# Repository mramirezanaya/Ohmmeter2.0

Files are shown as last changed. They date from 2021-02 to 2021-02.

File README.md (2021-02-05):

# Ohmmeter2.0

## 3D RGB Resistor

First the cables are soldered to the LEDs and the LED is glued on the piece inside the band. Each of the bands are mounted and glued together to build the resistance.

In the space between the bands, the white reference LEDs are soldered in parallel.

All cables are passed from one to another so that they all exit through the last.

Finally the two ends are glued and the resistance is finished.

## Assembling the Box

After printing all the pieces, we passed the resistance wires through the hole and soldered the terminations and the wires of the LEDs and the potentiometer.

The pcb is soldered according to the diagram and we connect all the wires.

## Programming

A state machine has been implemented to differentiate the modes.

### 'A' mode - Value to color
A value is entered by keyboard, it goes through an algorithm that returns its commercial value and displays it in the 3D resistor.

The program remains on active standby until a keyboard event arrives and if it is different from 'D' it shows the value on the screen and saves it in an array.
When pressing 'D', the array with the resistor value is passed to the "valor_a_comercial" function that converts the value into a commercial value and then, this array is passed to the "mostrar_resistencia" function that turns on the RGB LEDs of the 3D resistor with the right colors.

### 'B' mode - Color to value
The colors are entered and the value is displayed on the screen and the colors in the 3D resistor.

A legend is shown on the screen with the values and the corresponding number. The program saves the colors coded with numbers in an array and when pressing 'D' it shows the resistor value. While the colors are being entered, the RGB led of the corresponding band lights up.

### 'C' mode - Ohmmeter
This mode reads through the terminals and shows the value on the screen and the colors in the 3D resistor.

In order to measure various ranges, a potentiometer has been used. In a loop, the value of the potentiometer is read and this value is used as a reference to measure the connected resistor.
This process is repeated every programmable time (600 ms).

## Supplies:
- Arduino Mega

- 4 RGB Leds

- 3 Red Leds

- 3 White Leds

- 4 x 4 Membrane Switch Keypad

- OLED Display I2C 128 x 64 pixels and 0.96 Inch

- 2 connection terminals for resistors

- Potentiometer 50kΩ

- Resistors

    - 1kΩ x1
    - 220Ω x3
    - 22kΩ x1
    - 68Ω x1
- Pre-drilled plate

- 4 screws

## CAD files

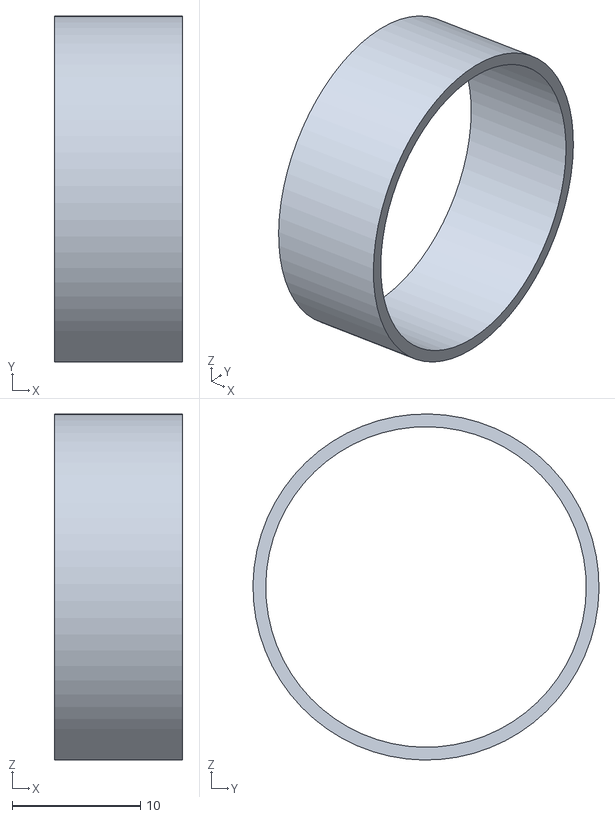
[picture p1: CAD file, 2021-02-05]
STLs/banda transparente.stl
10.0 x 27.0 x 27.0

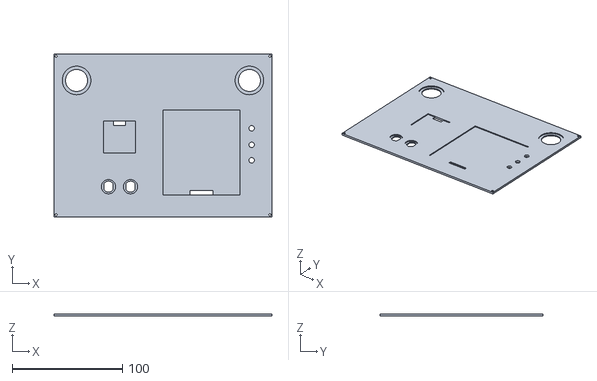
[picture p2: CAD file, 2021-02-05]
STLs/tapa.stl
198.0 x 148.0 x 2.00

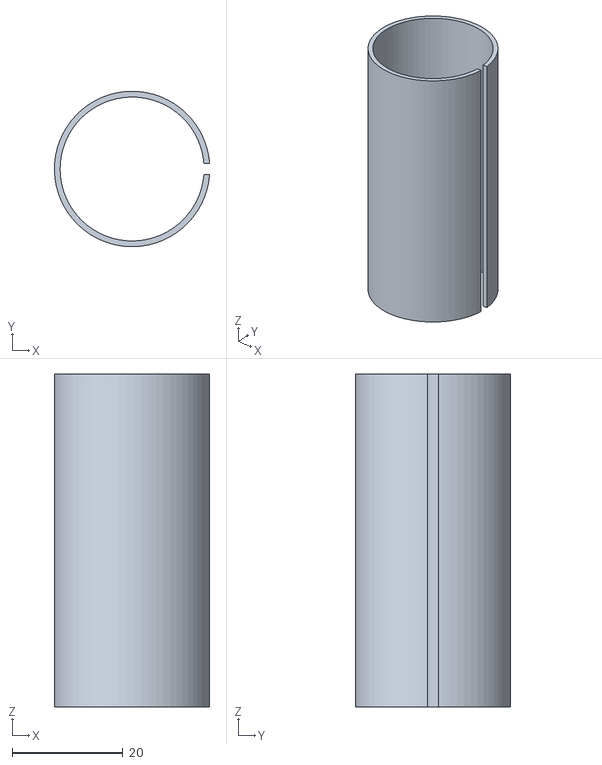
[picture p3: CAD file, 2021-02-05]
STLs/embellecedor.stl
28.0 x 28.0 x 60.0

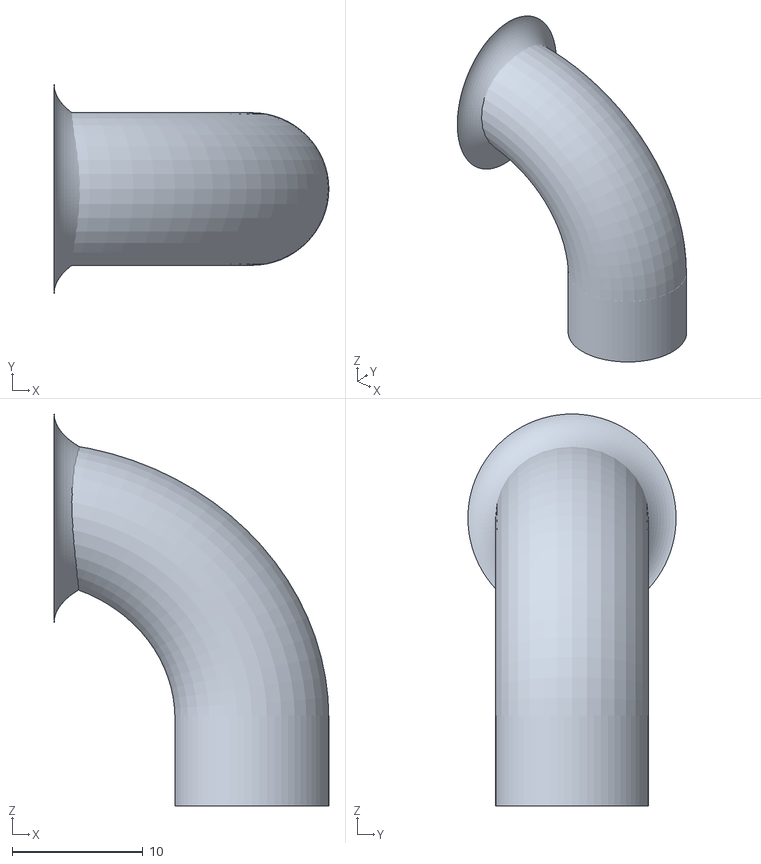
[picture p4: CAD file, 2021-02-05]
STLs/patilla.stl
21.0 x 15.9 x 30.0

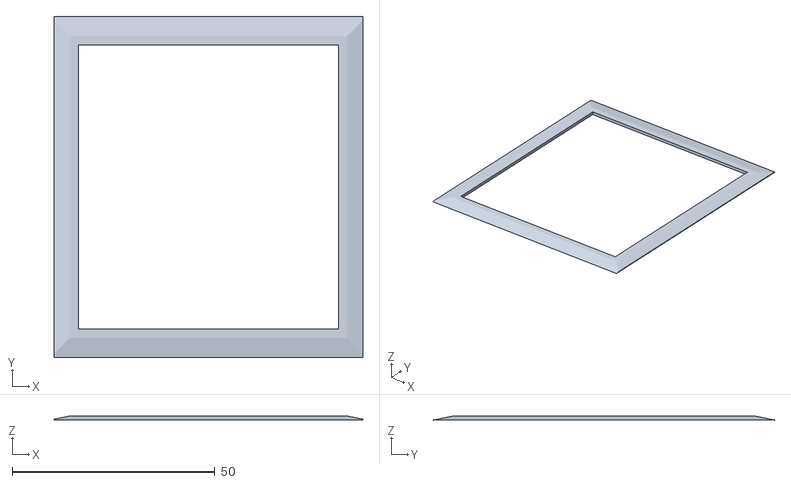
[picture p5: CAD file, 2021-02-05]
STLs/marco teclado.stl
76.0 x 84.0 x 1.00

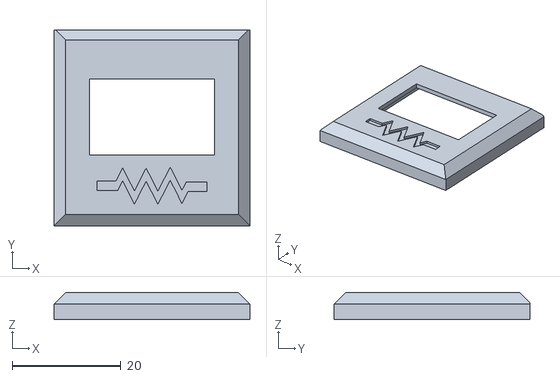
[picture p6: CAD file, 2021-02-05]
STLs/marco pantalla.stl
36.0 x 36.0 x 5.00

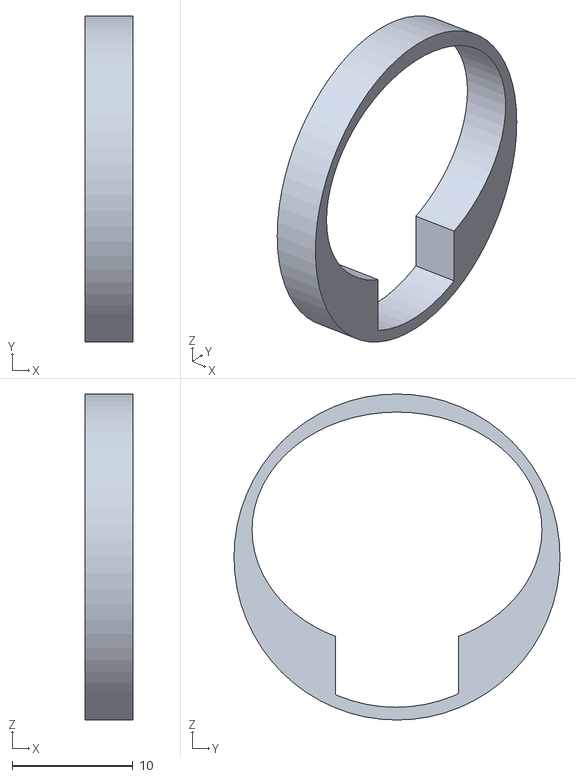
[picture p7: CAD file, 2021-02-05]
STLs/banda led blanco.stl
4.00 x 27.0 x 27.0

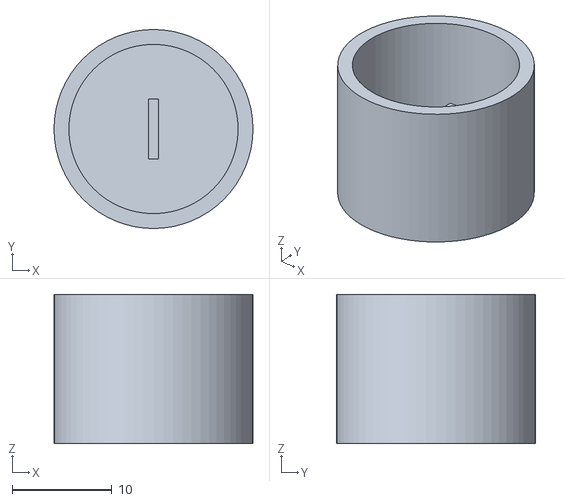
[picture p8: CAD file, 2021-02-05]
STLs/rueda.stl
20.0 x 20.0 x 15.0

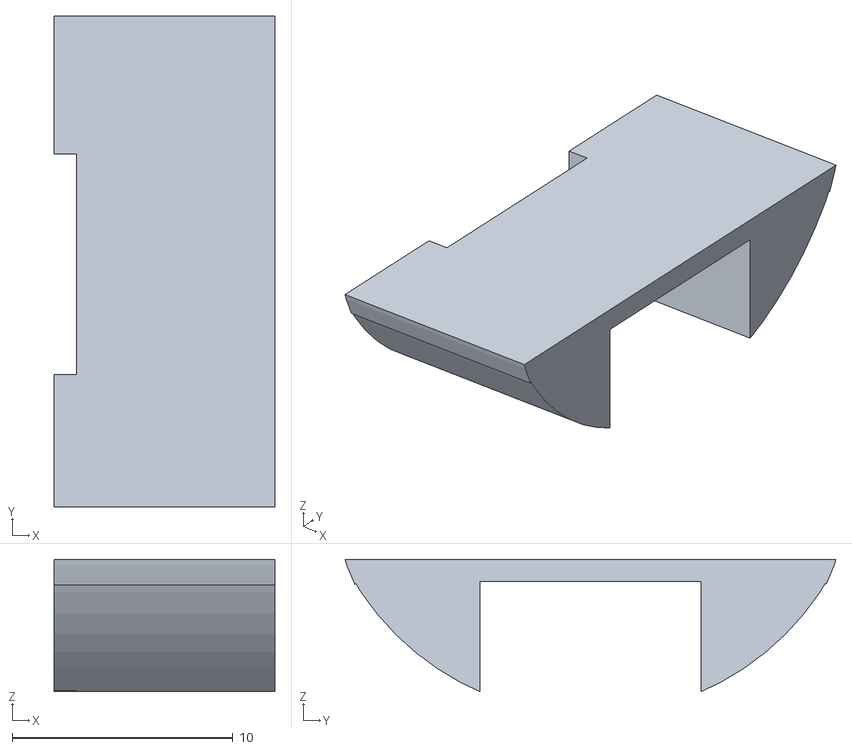
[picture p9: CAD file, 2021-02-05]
STLs/soporte led.stl
10.0 x 22.3 x 6.00

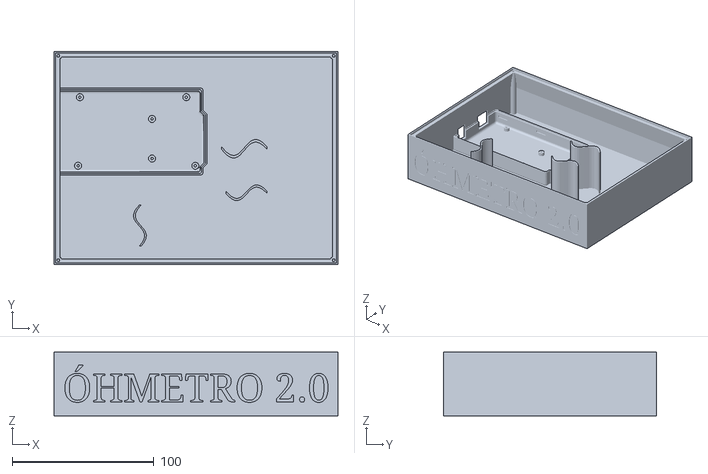
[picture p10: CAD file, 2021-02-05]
STLs/caja.stl
200.0 x 150.0 x 45.0

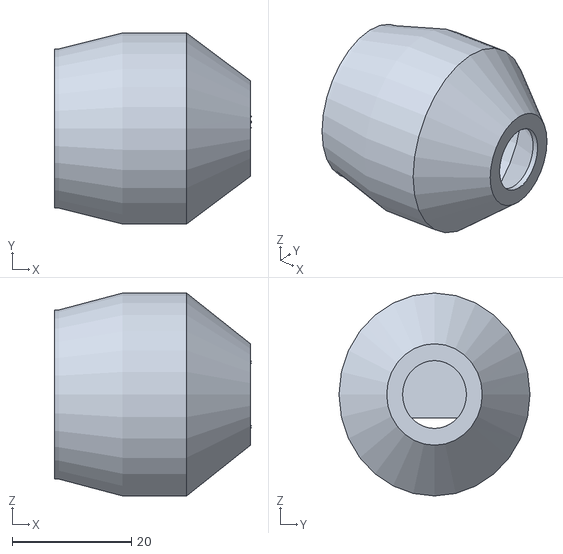
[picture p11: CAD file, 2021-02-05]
STLs/terminación.stl
33.0 x 32.0 x 34.0

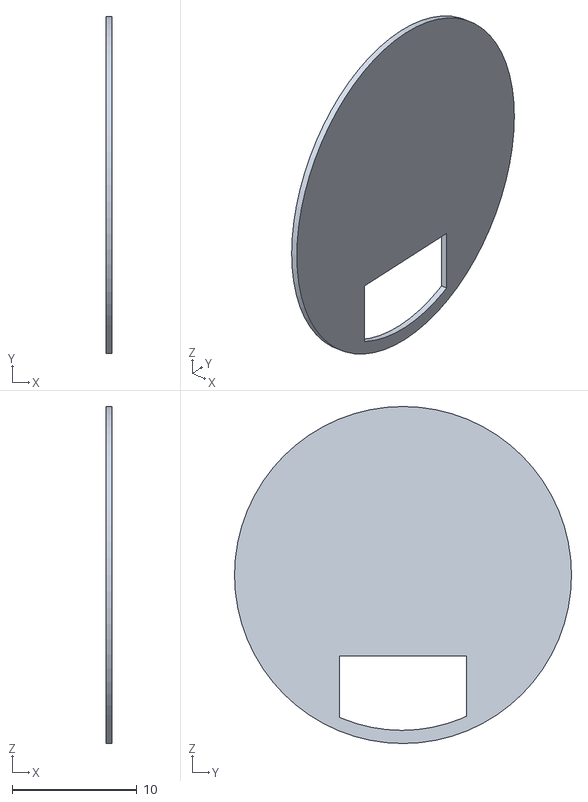
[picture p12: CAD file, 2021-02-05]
STLs/separador.stl
0.5 x 27.0 x 27.0

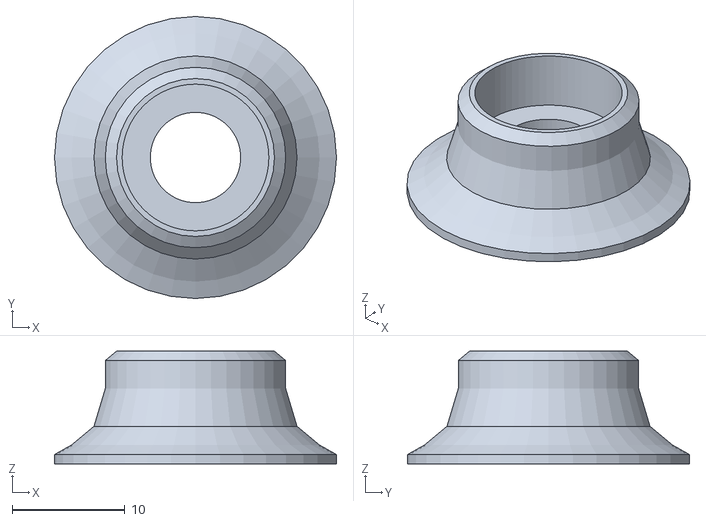
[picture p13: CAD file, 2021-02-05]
STLs/soporte resistencia.stl
25.0 x 25.0 x 10.0

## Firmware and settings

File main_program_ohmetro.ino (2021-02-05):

#include <SPI.h>
#include <Wire.h>
#include <Adafruit_GFX.h>
#include <Adafruit_SSD1306.h>
#include <Adafruit_Keypad.h>
 
// Definir constantes
#define ANCHO_PANTALLA 128 // ancho pantalla OLED
#define ALTO_PANTALLA 64 // alto pantalla OLED
#define BUFFER 20

#define BANDA1 1
#define BANDA2 2
#define BANDA3 3
#define BANDA4 4

#define modo_numero_a_color 0
#define modo_color_a_numero 1
#define modo_lee_resistencia 2
#define inicio 3

#define negro 0
#define marron 1
#define rojo 2
#define naranja 3
#define amarillo 4
#define verde 5
#define azul 6
#define violeta 7
#define gris 8
#define blanco 9

#define PERIODO 500

int x=0;
unsigned estado = inicio;

//globales del modo A
char a='x';
String cadena; 
char caracteres[BUFFER];
unsigned iA=0;
unsigned iB=0;

//globales modo C
unsigned long tiempo;
bool control=true;
float valor_pot, valor_res; //voltios
unsigned long r_pot=0, r_res=0, r_pot_ant=0, r_res_ant=0; //ohmios
unsigned long r_res_muestra=0, n_muestras=0;
unsigned long r_pot_muestra=0, n_muestras_pot=0;

//FUNCIONES
void pantalla(String cadena,unsigned tam,unsigned x,unsigned y);  //imprime por pantalla
void mostrar_resistencia(char valor[BUFFER]);                     
void colorea_banda(unsigned color,unsigned banda);
void rellena_color(unsigned array_color[3], unsigned color);
void apagar_resistencia();
void valor_a_comercial(char valor[BUFFER]);
unsigned short binary_lookup(int *A, int key, int imin, int imax);
void num_to_array(int long n, char res[BUFFER]);
int to_comercial(int valor);

// Objeto de la clase Adafruit_SSD1306
Adafruit_SSD1306 display(ANCHO_PANTALLA, ALTO_PANTALLA, &Wire, -1);

const byte ROWS = 4; // rows
const byte COLS = 4; // columns
//define the symbols on the buttons of the keypads
char keys[ROWS][COLS] = {
  {'1','2','3','A'},
  {'4','5','6','B'},
  {'7','8','9','C'},
  {'.','0','k','D'}
};
byte rowPins[ROWS] = {36, 34, 32,30}; //connect to the row pinouts of the keypad
byte colPins[COLS] = {28, 26, 24, 22}; //connect to the column pinouts of the keypad

//initialize an instance of class NewKeypad
Adafruit_Keypad customKeypad = Adafruit_Keypad( makeKeymap(keys), rowPins, colPins, ROWS, COLS);

void setup() {
  // put your setup code here, to run once:

#ifdef __DEBUG__
  Serial.begin(9600);
  delay(100);
  Serial.println("Iniciando pantalla OLED");
#endif
 
  // Iniciar pantalla OLED en la dirección 0x3C
  if (!display.begin(SSD1306_SWITCHCAPVCC, 0x3C)) {
#ifdef __DEBUG__
    Serial.println("No se encuentra la pantalla OLED");
#endif
    while (true);
  }
// Color del texto
display.setTextColor(SSD1306_WHITE);
display.clearDisplay();
display.display();
customKeypad.begin();

  
  
  pinMode(2, OUTPUT);
  pinMode(3, OUTPUT);
  pinMode(4, OUTPUT);
  pinMode(5, OUTPUT);
  pinMode(6, OUTPUT);
  pinMode(7, OUTPUT);
  pinMode(8, OUTPUT);
  pinMode(9, OUTPUT);
  pinMode(10, OUTPUT);
  pinMode(11, OUTPUT);
  pinMode(12, OUTPUT);
  pinMode(13, OUTPUT);
  pinMode(46, OUTPUT);
  pinMode(44, OUTPUT);
  pinMode(42, OUTPUT);
  pinMode(40, OUTPUT);
  pinMode(52, OUTPUT);
  pinMode(50, OUTPUT);


}

void loop() {
  customKeypad.tick();
  display.display();
  switch (estado){
      case inicio:
        apagar_resistencia();
        digitalWrite(44, LOW); //A
        digitalWrite(42, LOW);  //B
        digitalWrite(40, LOW);  //C
        pantalla("Select mode",1,8,5);
        pantalla("A:Num->col\nB:Col->num\nC:Read",2,0,15);
          while(customKeypad.available()){
             keypadEvent e = customKeypad.read();
            if(e.bit.EVENT == KEY_JUST_PRESSED){
              display.clearDisplay();
              switch((char)e.bit.KEY){
                case 'A':
                  a='x';
                  pantalla("A",3,50,20);
                  display.display();
                  estado=modo_numero_a_color;
                  delay(1000);
                  display.clearDisplay();
                break;
                case 'B':
                  pantalla("B",3,50,20);
                  display.display();
                  estado=modo_color_a_numero;
                  cadena="";
                  apagar_resistencia();
                  a='x';
                  delay(1000);
                  display.clearDisplay();
                  pantalla("Enter Col & press D",1,0,0);
                  pantalla("0 Black     1 Brown\n2 Red       3 Orange\n4 Yellow    5 Green\n6 Blue      7 Purple\n8 Grey      9 White",1,0,10);
                break;
                case 'C':
                  pantalla("C",3,50,20);
                  display.display();
                  estado=modo_lee_resistencia;
                  delay(1000);
                  display.clearDisplay();
                break;
              }
            }
          }
      break;
      case modo_numero_a_color:                     ////  A /////////////////////////////
        digitalWrite(44, HIGH); //A
        digitalWrite(42, LOW);  //B
        digitalWrite(40, LOW);  //C

        pantalla("Introduce Value",1,0,0);
        
        if(a!='D'){
          
          while(customKeypad.available()){
             keypadEvent e = customKeypad.read();
             // Limpiar buffer
            if(e.bit.EVENT == KEY_JUST_PRESSED){
              if(iA==0){
                display.clearDisplay();
                pantalla("Introduce Value",1,0,0);
              }
              a=(char)e.bit.KEY;
              caracteres[iA]=a;
              iA++;
              if(a!='D'){
                cadena=cadena+(char)e.bit.KEY;
                pantalla(cadena,2,10,15);
              }else{
                cadena=cadena + " ohm";
                pantalla(cadena,2,10,15);
                apagar_resistencia(); //retardo antes de montrar
                delay(500);
              }
            }
          }
        }else{
          valor_a_comercial(caracteres);
          mostrar_resistencia(caracteres);
          cadena=""; 
          iA=0;
          while(customKeypad.available()){
             keypadEvent e = customKeypad.read();
             // Limpiar buffer
            if(e.bit.EVENT == KEY_JUST_PRESSED){
              display.clearDisplay();
              switch((char)e.bit.KEY){
                case 'A':
                  display.clearDisplay();
                  apagar_resistencia();
                  a='x';
                  pantalla("Introduce Value",1,0,0);
                break;
                case 'B':
                  pantalla("B",3,50,20);
                  display.display();
                  estado=modo_color_a_numero;
                  apagar_resistencia();
                  cadena="";
                  a='x';
                  delay(1000);
                  display.clearDisplay();
                  pantalla("Enter Col & press D",1,0,0);
                  pantalla("0 Black     1 Brown\n2 Red       3 Orange\n4 Yellow    5 Green\n6 Blue      7 Purple\n8 Grey      9 White",1,0,10);
                break;
                case 'C':
                  pantalla("C",3,50,20);
                  display.display();
                  estado=modo_lee_resistencia;
                  apagar_resistencia();
                  delay(1000);
                  display.clearDisplay();
                break;
                case 'D':
                  estado = inicio;
                  display.clearDisplay();
                  delay(500);
                break;
                default:
                  if(iA==0){
                    display.clearDisplay();
                    pantalla("Introduce Value",1,0,0);
                  }
                  a=(char)e.bit.KEY;
                  caracteres[iA]=a;
                  iA++;
                  if(a!='D'){
                    cadena=cadena+(char)e.bit.KEY;
                    pantalla(cadena,2,10,15);
                  }else{
                    cadena=cadena + " ohm";
                    pantalla(cadena,2,10,15);
                  }
                break;
              }
            }
          }
        }
        
       
      
      break;
      case modo_color_a_numero:     ///// B ///////////////////////////////
        digitalWrite(44, LOW); //A
        digitalWrite(42, HIGH);  //B
        digitalWrite(40, LOW);  //C
        
        if(a!='D'){
          
          while(customKeypad.available()){
             keypadEvent e = customKeypad.read();
             // Limpiar buffer
            if(e.bit.EVENT == KEY_JUST_PRESSED){
              a=(char)e.bit.KEY;
              colorea_banda(int(a)-48,iB+1);
              if(a!='D'){
                if(iB==2){
                  for(int j=0;j<int(a)-48;j++){
                      cadena=cadena+'0'; 
                  }
                  if(int(a)-48>=3 && int(a)-48<6){
                    cadena.remove(cadena.length()-3,3);
                    cadena=cadena + " k";
                  }else if(int(a)-48>=6){
                    cadena.remove(cadena.length()-6,6);
                    cadena=cadena + " M";
                  }else{
                    cadena=cadena + " ";
                  }
                }else if(iB==3){
                  if(int(a)-48==amarillo){
                      cadena=cadena+"ohm\n\n        %5";
                  }else if(int(a)-48==gris){
                      cadena=cadena+"ohm\n\n       %10";
                  }else if(int(a)-48==rojo){
                      cadena=cadena+"ohm\n\n        %2";
                  }else{
                    cadena=cadena+"";
                  }
                }else{
                  cadena=cadena+a;
                }
                iB++;
              }
            }
          }
        }else{
          digitalWrite(46, HIGH); //blanca
          iB=0;
          display.clearDisplay();
          pantalla(cadena,2,0,15);
          
          while(customKeypad.available()){
             keypadEvent e = customKeypad.read();
             // Limpiar buffer
            if(e.bit.EVENT == KEY_JUST_PRESSED){
              display.clearDisplay();
              switch((char)e.bit.KEY){
                case 'A':
                  pantalla("A",3,50,20);
                  display.display();
                  a='x';
                  cadena=""; 
                  iA=0;
                  apagar_resistencia();
                  estado=modo_numero_a_color;
                  delay(1000);
                  display.clearDisplay();
                break;
                case 'B':
                  apagar_resistencia();
                  a='x';
                  cadena="";
                  display.clearDisplay();
                  pantalla("Enter Col & press D",1,0,0);
                  pantalla("0 Black     1 Brown\n2 Red       3 Orange\n4 Yellow    5 Green\n6 Blue      7 Purple\n8 Grey      9 White",1,0,10);
                break;
                case 'C':
                  pantalla("C",3,50,20);
                  display.display();
                  apagar_resistencia();
                  estado=modo_lee_resistencia;
                  delay(1000);
                  display.clearDisplay();
                break;
                case 'D':
                  estado = inicio;
                  display.clearDisplay();
                  delay(500);
                break;
                default:
                  
                break;
              }
            }
          }
        }
      break;
      case modo_lee_resistencia:      ///// C ///////////////////////////////
        digitalWrite(44, LOW); //A
        digitalWrite(42, LOW);  //B
        digitalWrite(40, HIGH);  //C
        
        if(millis()-tiempo< PERIODO){
            if(control){ //lee potenciometro
              digitalWrite(52, HIGH);
              digitalWrite(50, LOW);
              valor_pot=analogRead(A2)/4;
              r_pot_muestra=(22000*(valor_pot*5/255))/(5-(valor_pot*5/255));
              r_pot=r_pot + r_pot_muestra;
              n_muestras_pot++;
            }else{  //lee bornas
              digitalWrite(52, LOW);
              digitalWrite(50, HIGH);
              valor_res=analogRead(A7)/4;
              r_res_muestra=(255*(65000-r_pot)/valor_res) - (65000-r_pot); //calibrar ///////////////////////////////////////////////////
              r_res=r_res + r_res_muestra;
              n_muestras++;
            }
            
          
        }else{
          control=!control;
          tiempo=millis(); 
          r_res=r_res/n_muestras;
          r_pot=r_pot/n_muestras_pot;
          //display.clearDisplay();
          if(control){
            if(abs(r_res-r_res_ant)>10 || abs(r_pot-r_pot_ant)>10){
                display.clearDisplay();
                pantalla("Rango (ohm)",1,0,0);
                if(valor_pot<50){
                   pantalla("100-1k",2,0,10);
                }else if(valor_pot<100){
                   pantalla("1k-10k",2,0,10);
                }else if(valor_pot<150){
                    pantalla("10k-100k",2,0,10);
                }else if(valor_pot<200){
                    pantalla("100k-1M",2,0,10);
                }
  
                if(r_res>1000000){
                  pantalla("INF",2,0,40);
                  apagar_resistencia();
                }else if(r_res==0){
                  pantalla("0",2,0,40);
                  apagar_resistencia();
                }else{
                  pantalla(String(r_res)+" ohm",2,0,40);
                  num_to_array(to_comercial(r_res),caracteres);
                  mostrar_resistencia(caracteres);
                }
                
              }
              r_res_ant=r_res;
              r_pot_ant=r_pot;
              r_res=0;
              n_muestras=0;
              r_pot=0;
              n_muestras_pot=0;
          }
        }
        
          while(customKeypad.available()){
             keypadEvent e = customKeypad.read();
             // Limpiar buffer
            if(e.bit.EVENT == KEY_JUST_PRESSED){
              display.clearDisplay();
              switch((char)e.bit.KEY){
                case 'A':
                  a='x';
                  apagar_resistencia();
                  pantalla("A",3,50,20);
                  display.display();
                  estado=modo_numero_a_color;
                  delay(1000);
                  display.clearDisplay();
                break;
                case 'B':
                  pantalla("B",3,50,20);
                  display.display();
                  estado=modo_color_a_numero;
                  apagar_resistencia();
                  a='x';
                  cadena="";
                  delay(1000);
                  display.clearDisplay();
                  pantalla("Enter Col & press D",1,0,0);
                  pantalla("0 Black     1 Brown\n2 Red       3 Orange\n4 Yellow    5 Green\n6 Blue      7 Purple\n8 Grey      9 White",1,0,10);
                break;
                case 'C':
                  pantalla("C",3,50,20);
                  display.display();
                  estado=modo_lee_resistencia;
                  delay(1000);
                  display.clearDisplay();
                break;
                case 'D':
                  estado = inicio;
                  display.clearDisplay();
                  delay(500);
                break;
                default:
                  
                break;
              }
          }
        }
      break;
      default:
      break; 
  }

}

void pantalla(String cadena,unsigned tam,unsigned x,unsigned y){
  // Tamaño del texto
  display.setTextSize(tam);
  //Pos
  display.setCursor(x, y);
  // Escribir texto
  display.println(cadena);

  //display.display();
}

void mostrar_resistencia(char valor[BUFFER]){ //1kD i=1  x=0  cont=3
  unsigned i=0, x=0;
  int cont=0;
  while(valor[i]!='D'){
    if(i<2+x && valor[i]!='.' && valor[i]!='k'){
      colorea_banda(int((valor[i]))-48,i+1-x);
    }else if(valor[i]=='0'){
       cont++;
    }else if(valor[i]=='k'){
       cont=cont+3;
    }
    else if(valor[i]=='.'){
      x++;
      cont=cont-1;
    }
    i++;
  }  
  colorea_banda(cont,3);
  colorea_banda(amarillo,4);
  digitalWrite(46, HIGH); //blanca
}

void colorea_banda(unsigned color,unsigned banda){
    unsigned array_color[3]; 
    rellena_color(array_color,color);
    switch (banda){
      case BANDA1:
        analogWrite(11,array_color[0]); //rojo 
        analogWrite(12,array_color[1]); //verde 
        analogWrite(13,array_color[2]); //azul
      break;
      case BANDA2:
        analogWrite(8,array_color[0]); //rojo 
        analogWrite(9,array_color[1]); //verde 
        analogWrite(10,array_color[2]); //azul
      break;
      case BANDA3:
        analogWrite(5,array_color[0]); //rojo 
        analogWrite(6,array_color[1]); //verde 
        analogWrite(7,array_color[2]); //azul
      break;
      case BANDA4:
        analogWrite(2,array_color[0]); //rojo 
        analogWrite(3,array_color[1]); //verde 
        analogWrite(4,array_color[2]); //azul
      break;
    }
}

void rellena_color(unsigned array_color[3], unsigned color){
    switch(color){
      case negro:
        array_color[0]=0;
        array_color[1]=0;
        array_color[2]=0;
      break;
      case marron:
        array_color[0]=30;
        array_color[1]=10;
        array_color[2]=0;
      break;
      case rojo:
        array_color[0]=255;
        array_color[1]=0;
        array_color[2]=0;
      break;
      case naranja:
        array_color[0]=255;
        array_color[1]=100;
        array_color[2]=0;
      break;
      case amarillo:
        array_color[0]=255;
        array_color[1]=255;
        array_color[2]=0;
      break;
      case verde:
        array_color[0]=0;
        array_color[1]=255;
        array_color[2]=0;
      break;
      case azul:
        array_color[0]=0;
        array_color[1]=0;
        array_color[2]=255;
      break;
      case violeta:
        array_color[0]=50;
        array_color[1]=0;
        array_color[2]=120;
      break;
      case gris:
        array_color[0]=10;
        array_color[1]=10;
        array_color[2]=10;
      break;
      case blanco:
        array_color[0]=255;
        array_color[1]=255;
        array_color[2]=255;
      break;
      default:
        array_color[0]=0;
        array_color[1]=0;
        array_color[2]=0;
      break;
    }
}

void apagar_resistencia(){
  digitalWrite(46, LOW); //blanca
    // BANDA 4
  analogWrite(2,0); //rojo 
  analogWrite(3,0); //verde 
  analogWrite(4,0); //azul 

// BANDA 3
  analogWrite(5,0); //rojo 
  analogWrite(6,0); //verde 
  analogWrite(7,0); //azul 
  
// BANDA 2
  analogWrite(8,0); //rojo 
  analogWrite(9,0); //verde 
  analogWrite(10,0); //azul 

// BANDA 1
  analogWrite(11,0); //rojo 
  analogWrite(12,0); //verde 
  analogWrite(13,0); //azul 

}

void valor_a_comercial(char valor[BUFFER]){
    int comerciales[14]={10,12,15,18,22,27,33,39,47,51,56,68,82,100};
    int valor_comercial;
    char copia[BUFFER];
    String cadena="";
    int z=0;
    int i=2;
    char sig;
    cadena=cadena + valor[0];
    if(valor[1]=='.'){
      cadena=cadena + valor[2];
    }else{
      cadena=cadena + valor[1];
    }
    valor_comercial=comerciales[binary_lookup(comerciales,cadena.toInt(),0,13)]; ///////cambio
    valor[0]=char((valor_comercial/10) + 48);
    if(valor[1]=='.'){
      valor[2]=char((valor_comercial%10) + 48);
      if(valor_comercial==100){
        i=1;
        while(valor[i+1]!='D'){ // 9.9kD -> 10kkD -> 10kD
          valor[i]=valor[i+1];
          i++;
        }
        valor[i]=valor[i+1];//10kDD
      }
    }else{
      valor[1]=char((valor_comercial%10) + 48);
      if(valor_comercial==100){
        for(int j=0;j<BUFFER;j++){
          copia[j]=valor[j];
        }
        i=2;
        while(copia[i]!='D'){
          valor[i+1]=copia[i];
          i++;
        }
        valor[i+1]=copia[i];
        valor[2]='0';
      }
    }
    
    cadena="";
    while(valor[z]!='D'){
      cadena=cadena+valor[z];
      z++;
    }
    cadena=cadena+ " ohm";
    pantalla("Commercial Value",1,0,35);
    pantalla(cadena,2,10,50);
    
}

int to_comercial(int valor){
  unsigned long mult=0;
  int comerciales[14]={10,12,15,18,22,27,33,39,47,51,56,68,82,100};
  if(valor<100){
      mult=1;
  }else if(valor<1000){
      mult=10;
  }else if(valor<10000){
      mult=100;
  }else if(valor<100000){
      mult=1000;
  }else if(valor<1000000){
      mult=10000;
  }
  valor=valor/mult;
  valor=comerciales[binary_lookup(comerciales,valor,0,13)]*mult;
  return valor;
}

void num_to_array(int long n, char res[BUFFER]){
  unsigned long mult=0;
  int i=2,m=10;
  if(n<100){
      mult=10;
  }else if(n<1000){
      mult=100;
  }else if(n<10000){
      mult=1000;
  }else if(n<100000){
      mult=10000;
  }else if(n<1000000){
      mult=100000;
  }
  res[0]=char (n/mult) + 48;
  res[1]=char(((n%mult)/(mult/10)))+48;
  while(m<mult){
    res[i]='0';
    m=m*10;
    i++;
  }
  res[i]='D';
}

unsigned short binary_lookup(int *A, int key, int imin, int imax)
{
   int pos=0;
  int w=0;
  int diferencia,diferencia_ant=100;

  while (w<=imax)
    {
      diferencia=abs(key-A[w]);
      if(diferencia<diferencia_ant){
        pos=w;
      }
      diferencia_ant=diferencia;
      w++;
    }
    return pos;    //Al final imax=imin y en dicha posicion hay un numero mayor o igual que el buscado
}
